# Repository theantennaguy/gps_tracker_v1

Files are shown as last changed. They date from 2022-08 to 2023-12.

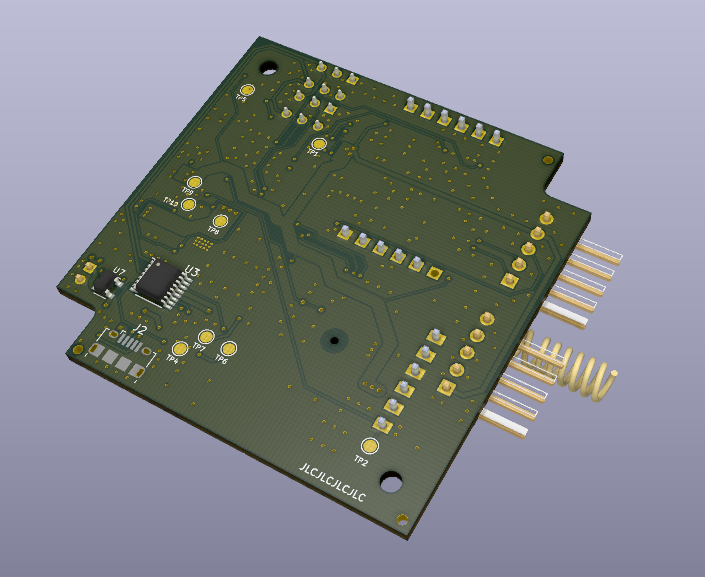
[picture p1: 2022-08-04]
hardware/images/2020-11-08_board_3.png

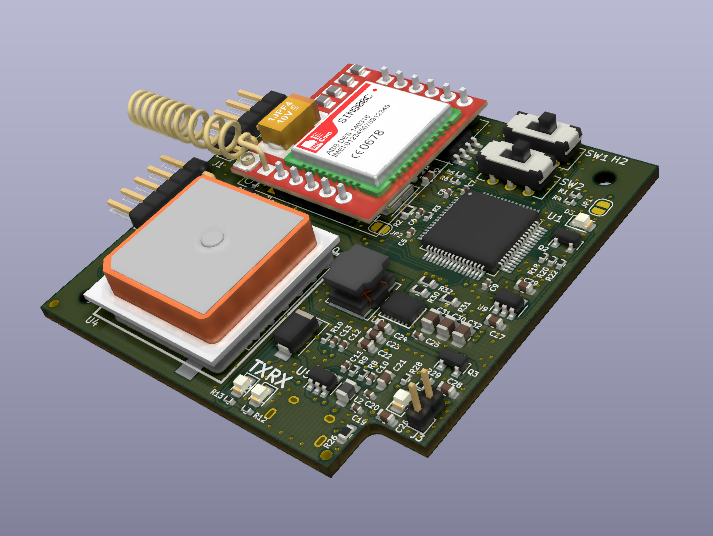
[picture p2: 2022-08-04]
hardware/images/2020-11-08_board_2.png

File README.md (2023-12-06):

# gps_tracker_v1
 
This project is discontinued. I'm working on a new version, but so far it's only in the design phase.

The hardware project for this project is complete and functional. A board-bring-up was sucessfully performed and all is operational. The code was never completed, only basic functions for capturing GPS coordinates and sending SMSs, but I never got ot finish a working application for it.

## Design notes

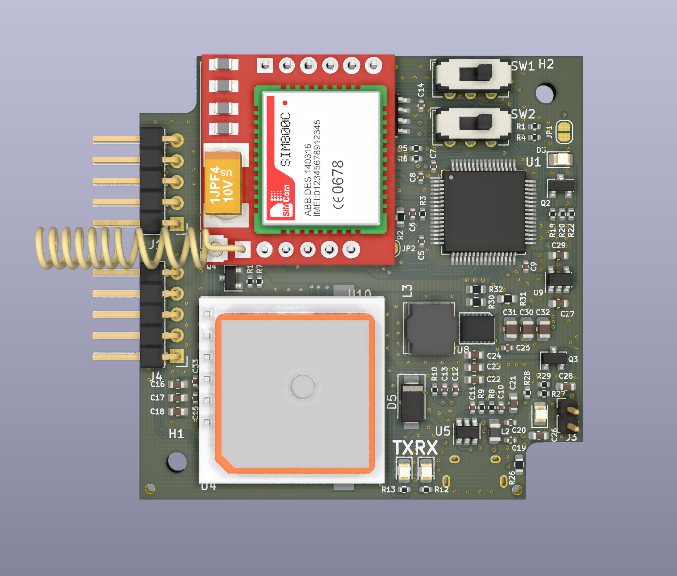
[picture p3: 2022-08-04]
hardware/images/2020-11-08_board.png

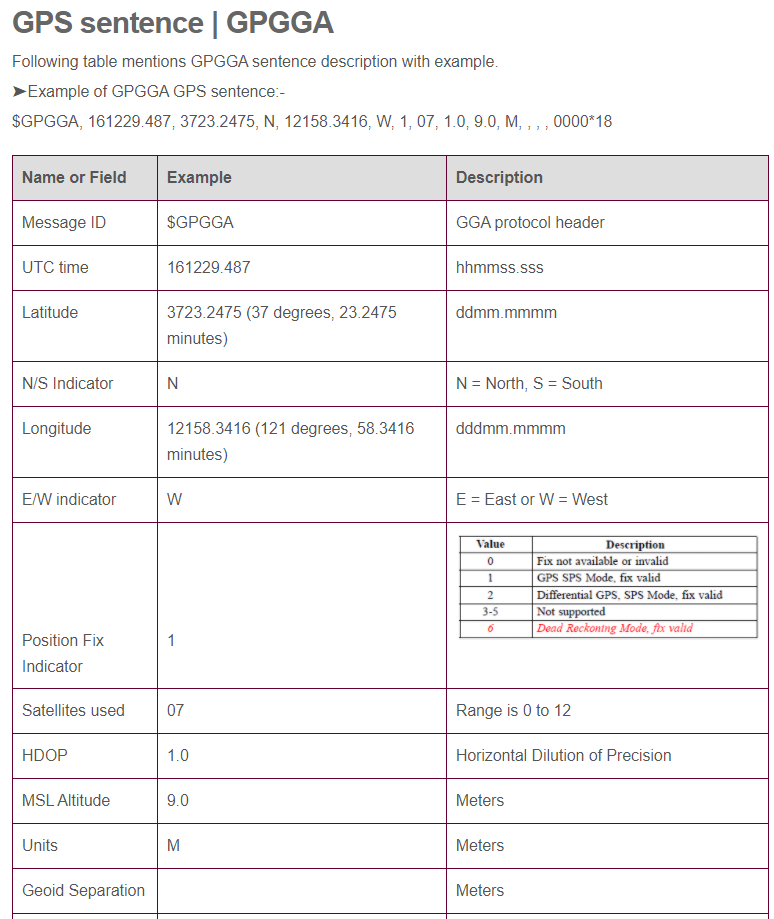
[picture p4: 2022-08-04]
hardware/pdf/GPGGA_message_structure.png

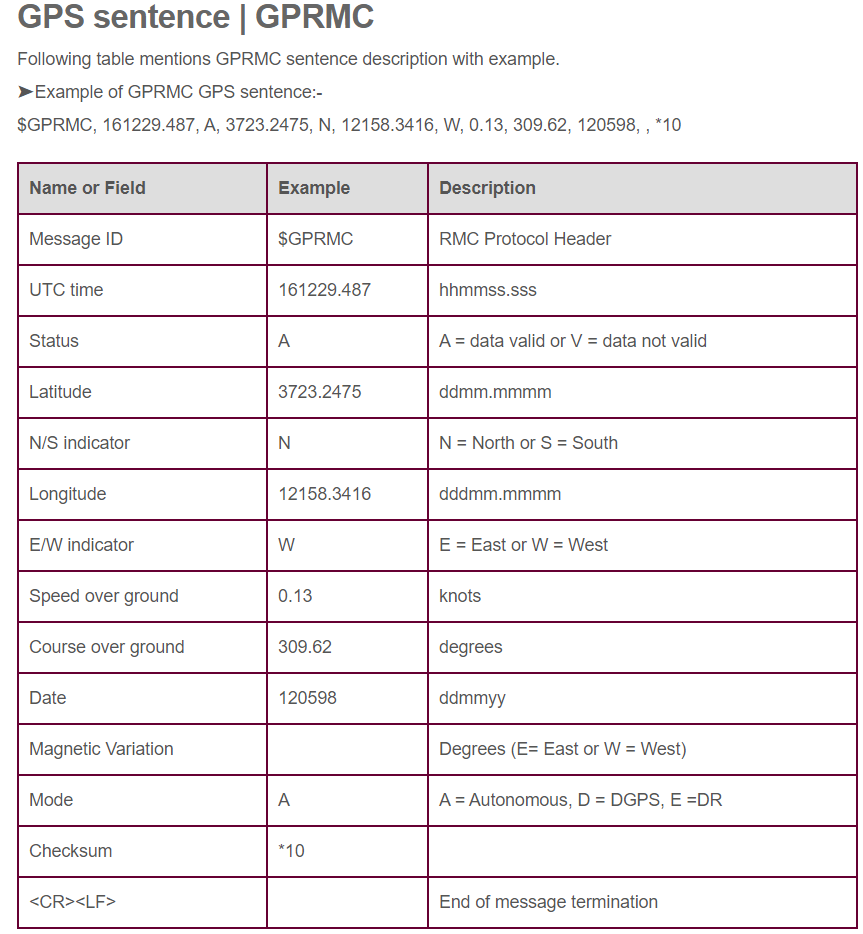
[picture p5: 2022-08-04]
hardware/pdf/GPRMC_message_structure.png

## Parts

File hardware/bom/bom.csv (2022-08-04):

Reference | Quantity | Value | Footprint | LCSC | Manufacturer | Mfr. PN | Supplier | Supplier PN
C1 C2 | 2 | 12pF | Capacitor_SMD:C_0402_1005Metric | C1547 | Guangdong Fenghua Advanced Tech | 0402CG120J500NT | LCSC | C1547
C10 C11 | 2 | 47pF | Capacitor_SMD:C_0402_1005Metric | C1567 | Guangdong Fenghua Advanced Tech | 0402CG470J500NT | LCSC | C1567
C5 C6 C7 C8 C9 C12 C13 C14 C15 C19 C20 C25 C33 | 13 | 100nF | Capacitor_SMD:C_0402_1005Metric | C1525 | Samsung Electro-Mechanics | CL05B104KO5NNNC | LCSC | C1525
C16 C17 C18 C22 C23 | 5 | 10uF | Capacitor_SMD:C_0603_1608Metric | C19702 | Samsung Electro-Mechanics | CL10A106KP8NNNC | LCSC | C19702
C3 C21 | 2 | 4.7uF | Capacitor_SMD:C_0603_1608Metric | C19666 | SAMSUNG | CL10A475KO8NNNC | LCSC | C19666
C30 C31 C32 | 3 | 22uF | Resistor_SMD:R_0805_2012Metric | C45783 | Samsung Electro-Mechanics | CL21A226MAQNNNE | LCSC | C45783
C4 C24 C26 C27 C28 C29 | 6 | 1uF | Capacitor_SMD:C_0603_1608Metric | C15849 | Samsung Electro-Mechanics | CL10A105KB8NNNC | LCSC | C15849
D1 | 1 | YELLOW | LED_SMD:LED_0805_2012Metric | C2296 | Hubei KENTO Elec | 17-21SUYC/TR8 | LCSC | C2296
D2 D3 D4 | 3 | RED | LED_SMD:LED_0805_2012Metric | C84256 | Foshan NationStar Optoelectronics | FC-2012HRK-620D | LCSC | C84256
D5 | 1 | SS14 | Diode_SMD:D_SMA | C2480 | MDD( Microdiode Electronics) | SS14 | LCSC | C2480
Q1 Q2 Q4 | 3 | S8050 | Package_TO_SOT_SMD:SOT-23 | C2146 | Changjiang Electronics Tech (CJ) | S8050 | LCSC | C2146
Q3 | 1 | Si2301CDS | Package_TO_SOT_SMD:SOT-23 | C10487 | Vishay Intertech | SI2301CDS-T1-GE3 | LCSC | C10487
R12 R13 R22 R27 | 4 | 330 | Resistor_SMD:R_0402_1005Metric | C25104 | Uniroyal Elec | 0402WGF3300TCE | LCSC | C25104
R4 R10 R14 R15 R23 R24 | 6 | 1k | Resistor_SMD:R_0402_1005Metric | C11702 | Uniroyal Elec | 0402WGF1001TCE | LCSC | C11702
R16 R25 | 2 | 5k6 | Resistor_SMD:R_0402_1005Metric | C25908 | Uniroyal Elec | 0402WGF5601TCE | LCSC | C25908
R7 R17 R18 | 3 | 4.7k | Resistor_SMD:R_0402_1005Metric | C25900 | Uniroyal Elec | 0402WGF4701TCE | LCSC | C25900
R11 R19 R20 | 3 | 47k | Resistor_SMD:R_0402_1005Metric | C25792 | Uniroyal Elec | 0402WGF4702TCE | LCSC | C25792
R1 R3 R5 R6 R21 R29 R33 | 7 | 10k | Resistor_SMD:R_0402_1005Metric | C25744 | Uniroyal Elec | 0402WGF1002TCE | LCSC | C25744
R26 | 1 | 100k | Resistor_SMD:R_0603_1608Metric | C25803 | Uniroyal Elec | 0603WAF1003T5E | LCSC | C25803
R28 | 1 | 2k | Resistor_SMD:R_0402_1005Metric | C4109 | Uniroyal Elec | 0402WGF2001TCE | LCSC | C4109
R31 | 1 | 150k | Resistor_SMD:R_0603_1608Metric | C22807 | Uniroyal Elec | 0603WAF1503T5E | LCSC | C22807
R30 R32 | 2 | 1M | Resistor_SMD:R_0603_1608Metric | C22935 | Uniroyal Elec | 0603WAF1004T5E | LCSC | C22935
U2 | 1 | CAT24C256 | Package_SO:SOIC-8_3.9x4.9mm_P1.27mm | C6482 | Microchip Tech | AT24C256C-SSHL-T | LCSC | C6482
U8 | 1 | TPS63020 | gps_tracker:QFN14_P0.5_4.15x3.15_wThermalVias | C15483 | Texas Instruments | TPS63020DSJR | LCSC | C15483

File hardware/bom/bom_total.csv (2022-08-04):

Reference | Quantity | Value | Footprint | LCSC | Manufacturer | Mfr. PN | Supplier | Supplier PN
C1 C2 | 2 | 12pF | Capacitor_SMD:C_0402_1005Metric | C1547 | Guangdong Fenghua Advanced Tech | 0402CG120J500NT | LCSC | C1547
C10 C11 | 2 | 47pF | Capacitor_SMD:C_0402_1005Metric | C1567 | Guangdong Fenghua Advanced Tech | 0402CG470J500NT | LCSC | C1567
C5 C6 C7 C8 C9 C12 C13 C14 C15 C19 C20 C25 C33 | 13 | 100nF | Capacitor_SMD:C_0402_1005Metric | C1525 | Samsung Electro-Mechanics | CL05B104KO5NNNC | LCSC | C1525
C16 C17 C18 C22 C23 | 5 | 10uF | Capacitor_SMD:C_0603_1608Metric | C19702 | Samsung Electro-Mechanics | CL10A106KP8NNNC | LCSC | C19702
C3 C21 | 2 | 4.7uF | Capacitor_SMD:C_0603_1608Metric | C19666 | Samsung Electro-Mechanics | CL10A475KO8NNNC | LCSC | C19666
C30 C31 C32 | 3 | 22uF | Resistor_SMD:R_0805_2012Metric | C45783 | Samsung Electro-Mechanics | CL21A226MAQNNNE | LCSC | C45783
C4 C24 C26 C27 C28 C29 | 6 | 1uF | Capacitor_SMD:C_0603_1608Metric | C15849 | Samsung Electro-Mechanics | CL10A105KB8NNNC | LCSC | C15849
D1 | 1 | YELLOW | LED_SMD:LED_0805_2012Metric | C2296 | Hubei KENTO Elec | 17-21SUYC/TR8 | LCSC | C2296
D2 D3 D4 | 3 | RED | LED_SMD:LED_0805_2012Metric | C84256 | Foshan NationStar Optoelectronics | FC-2012HRK-620D | LCSC | C84256
D5 | 1 | SS14 | Diode_SMD:D_SMA | C2480 | MDD( Microdiode Electronics) | SS14 | LCSC | C2480
H1 H2 | 2 | MountingHole | MountingHole:MountingHole_2.5mm
J1 J4 | 2 | Conn_01x05 | Connector_PinHeader_2.54mm:PinHeader_1x05_P2.54mm_Horizontal | - | - | -
J2 | 1 | USB_B_Micro | Connector_USB:USB_Micro-B_Amphenol_10118194_Horizontal | - | Amphenol | 10118194-0001LF | Mouser | 649-10118194-0001LF
J3 | 1 | Battery | Connector_PinHeader_2.00mm:PinHeader_1x02_P2.00mm_Vertical | - | - | -
JP1 JP2 | 2 | JP | Jumper:SolderJumper-2_P1.3mm_Open_RoundedPad1.0x1.5mm | - | - | -
L1 | 1 | 220 Ohm | Inductor_SMD:L_0603_1608Metric | C85826 | Murata Electronics | BLM18BB221SN1D | Mouser | 81-BLM18BB221SN1D
L2 | 1 | 330 Ohm | Inductor_SMD:L_0805_2012Metric | - | Murata Electronics | BLM21PG331SN1D | Mouser | 81-BLM21P331SG
L3 | 1 | 1.5uH | Inductor_SMD:L_Bourns_SRN6045TA | - | Bourns | SRN6045TA-1R5Y | Mouser | 652-SRN6045TA-1R5Y
Q1 Q2 Q4 | 3 | S8050 | Package_TO_SOT_SMD:SOT-23 | C2146 | Changjiang Electronics Tech (CJ) | S8050 | LCSC | C2146
Q3 | 1 | Si2301CDS | Package_TO_SOT_SMD:SOT-23 | C10487 | Vishay Intertech | SI2301CDS-T1-GE3 | LCSC | C10487
R12 R13 R22 R27 | 4 | 330 | Resistor_SMD:R_0402_1005Metric | C25104 | Uniroyal Elec | 0402WGF3300TCE | LCSC | C25104
R4 R10 R14 R15 R23 R24 | 6 | 1k | Resistor_SMD:R_0402_1005Metric | C11702 | Uniroyal Elec | 0402WGF1001TCE | LCSC | C11702
R16 R25 | 2 | 5k6 | Resistor_SMD:R_0402_1005Metric | C25908 | Uniroyal Elec | 0402WGF5601TCE | LCSC | C25908
R7 R17 R18 | 3 | 4.7k | Resistor_SMD:R_0402_1005Metric | C25900 | Uniroyal Elec | 0402WGF4701TCE | LCSC | C25900
R11 R19 R20 | 3 | 47k | Resistor_SMD:R_0402_1005Metric | C25792 | Uniroyal Elec | 0402WGF4702TCE | LCSC | C25792
R1 R3 R5 R6 R21 R29 R33 | 7 | 10k | Resistor_SMD:R_0402_1005Metric | C25744 | Uniroyal Elec | 0402WGF1002TCE | LCSC | C25744
R26 | 1 | 100k | Resistor_SMD:R_0603_1608Metric | C25803 | Uniroyal Elec | 0603WAF1003T5E | LCSC | C25803
R28 | 1 | 2k | Resistor_SMD:R_0402_1005Metric | C4109 | Uniroyal Elec | 0402WGF2001TCE | LCSC | C4109
R31 | 1 | 150k | Resistor_SMD:R_0603_1608Metric | C22807 | Uniroyal Elec | 0603WAF1503T5E | LCSC | C22807
R30 R32 | 2 | 1M | Resistor_SMD:R_0603_1608Metric | C22935 | Uniroyal Elec | 0603WAF1004T5E | LCSC | C22935
R8 R9 | 2 | 27 | Resistor_SMD:R_0402_1005Metric | - | YAGEO | RT0402FRE0727RL | Mouser | 603-RT0402FRE0727R
SW1 SW2 | 2 | SW_Push_DPDT | Button_Switch_THT:SW_CuK_JS202011CQN_DPDT_Straight | - | C&K | JS202011JCQN | Mouser | 611-JS202011JCQN
TP1 | 1 | 3V3_MCU | TestPoint:TestPoint_Pad_D1.5mm | -
TP10 | 1 | PGOOD | TestPoint:TestPoint_Pad_D1.5mm | -
TP2 | 1 | PPS | TestPoint:TestPoint_Pad_D1.5mm | -
TP4 TP5 | 2 | GND | TestPoint:TestPoint_Pad_D1.5mm | -
TP6 | 1 | USB | TestPoint:TestPoint_Pad_D1.5mm | -
TP7 | 1 | 5V0 | TestPoint:TestPoint_Pad_D1.5mm | -
TP8 | 1 | 4V0 | TestPoint:TestPoint_Pad_D1.5mm | -
TP9 | 1 | 3V3 | TestPoint:TestPoint_Pad_D1.5mm | -
U1 | 1 | STM32F030R8Tx | Package_QFP:LQFP-64_10x10mm_P0.5mm | C39105 | STMicroelectronics | STM32F030R8T6 | Mouser | -
U10 | 1 | L80-RE | gps_tracker:L80RE | - | Quectel | L80RE-M37 | Mouser | 277-L80RE-M37
U2 | 1 | CAT24C256 | Package_SO:SOIC-8_3.9x4.9mm_P1.27mm | C6482 | Microchip Tech | AT24C256C-SSHL-T | LCSC | C6482
U3 | 1 | FT230XS | Package_SO:SSOP-16_3.9x4.9mm_P0.635mm | - | FTDI | FT230XS | Mouser | 895-FT230XS-R
U4 | 1 | UP501B | gps_tracker:UP501B | - | Fastrax | UP501B | Mouser | -
U5 | 1 | USBLC6 | Package_TO_SOT_SMD:SOT-23-6 | C7519 | STMicroelectronics | USBLC6-2SC6 | Mouser | 511-USBLC6-2SC6
U6 | 1 | SIM800L | gps_tracker:SIM_800L_breakout | - | SIM | SIM800L | - | -
U7 | 1 | MCP73812T-420I-OT | Package_TO_SOT_SMD:SOT-23-5 | C144308 | Microchip Tech | MCP73812T-420I/OT | Mouser | 579-MCP73812T-420IOT
U8 | 1 | TPS63020 | gps_tracker:QFN14_P0.5_4.15x3.15_wThermalVias | C15483 | Texas Instruments | TPS63020DSJR | Mouser | 595-TPS63020DSJR
U9 | 1 | LP5907MFX-3.3 | Package_TO_SOT_SMD:SOT-23-5 | C80670 | Texas Instruments | LP5907MFX-3.3/NOPB | Mouser | 595-LP5907QMFX-3.3Q1
Y1 | 1 | 8 MHz | Crystal:Crystal_SMD_5032-2Pin_5.0x3.2mm | - | ECS | ECS-80-12-30Q-DS-TR | Mouser | 520-80-12-30Q-DST

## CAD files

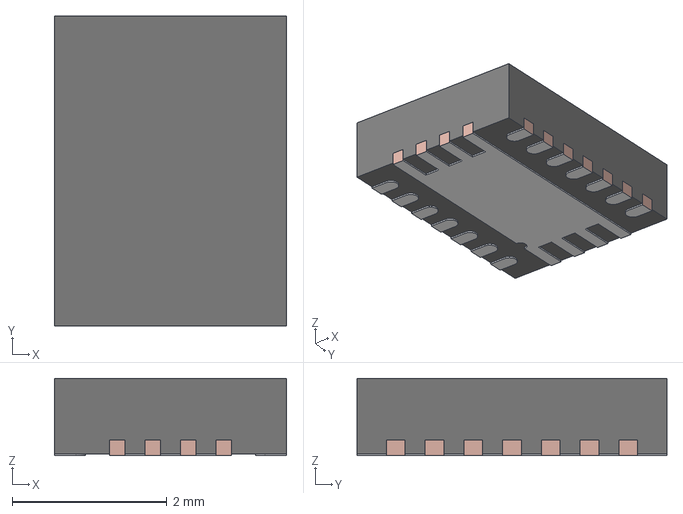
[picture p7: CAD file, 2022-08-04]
hardware/3d_models/DSJ0014A.stp
3.00 x 4.00 x 1.00 mm
FRAME
MOLD

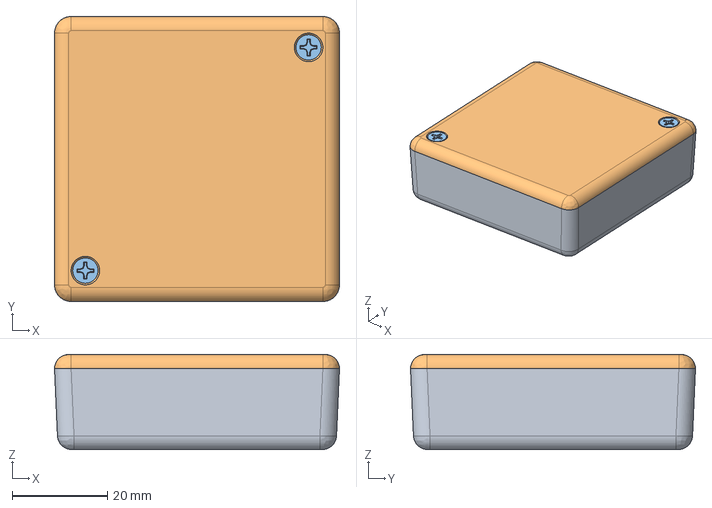
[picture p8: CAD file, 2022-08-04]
hardware/3d_models/1551TTBU.stp
60.0 x 60.0 x 20.0 mm
1551T Box
1551T Lid

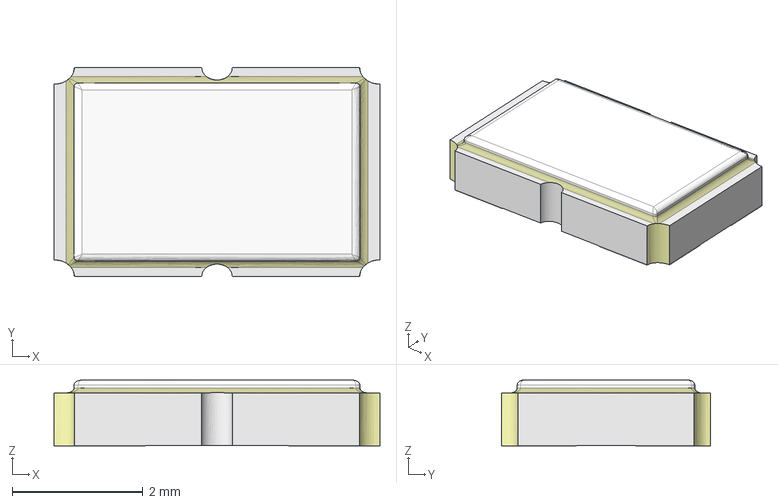
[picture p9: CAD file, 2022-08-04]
hardware/3d_models/xtal_osc_5x3.2.step
4.99 x 3.20 x 1.01 mm

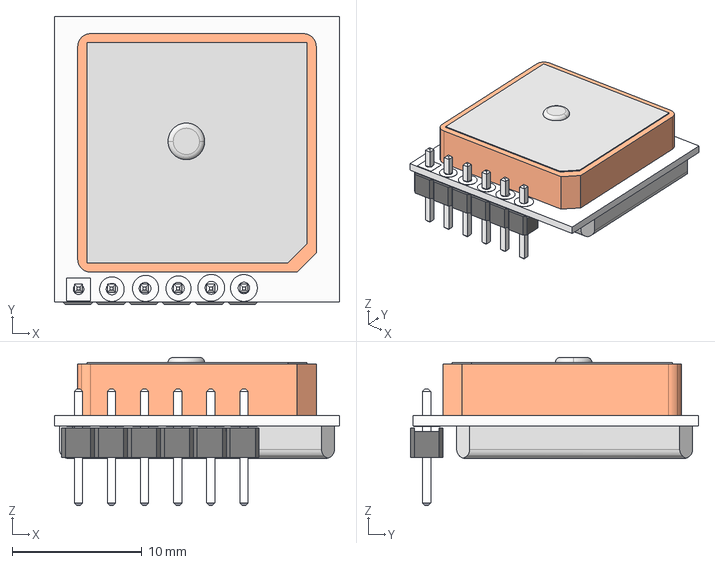
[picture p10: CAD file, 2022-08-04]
hardware/3d_models/fastrax_up501b.step
22.0 x 22.2 x 11.4 mm

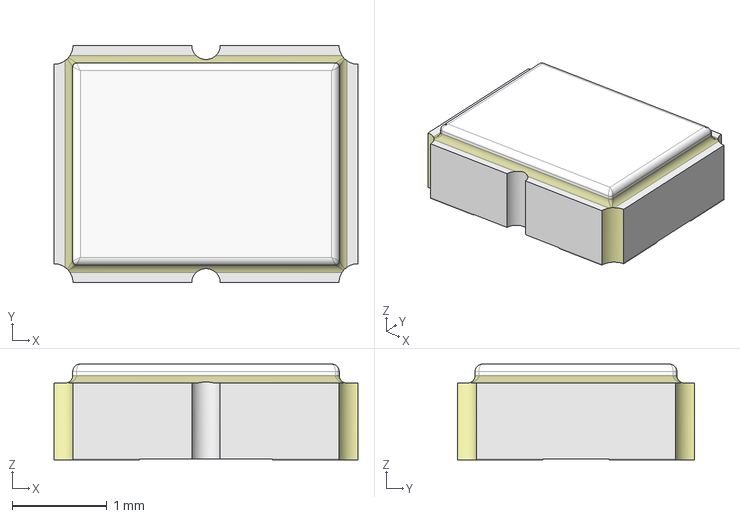
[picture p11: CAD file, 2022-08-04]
hardware/3d_models/xtal_osc_3.2x2.5.step
3.20 x 2.50 x 1.01 mm

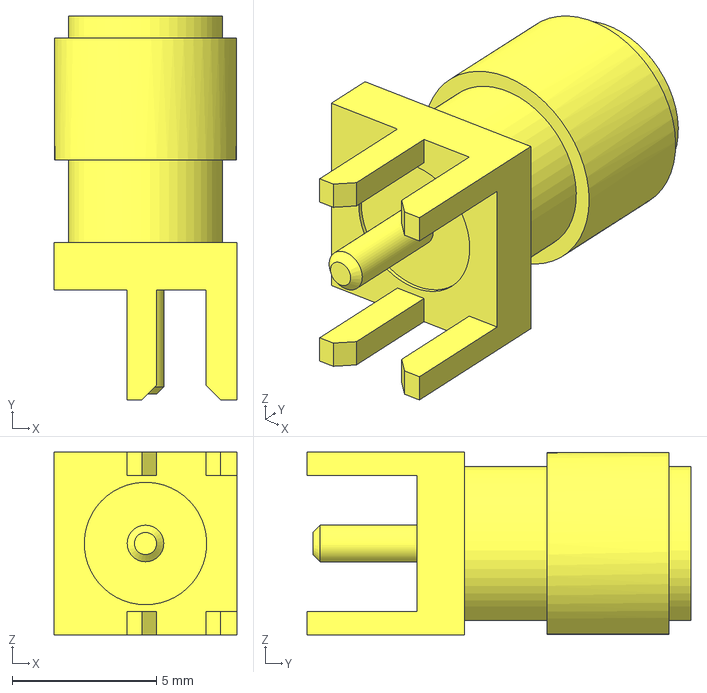
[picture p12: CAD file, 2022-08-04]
hardware/3d_models/SMA-J-P-H-ST-EM1.stp
6.35 x 13.3 x 6.35 mm

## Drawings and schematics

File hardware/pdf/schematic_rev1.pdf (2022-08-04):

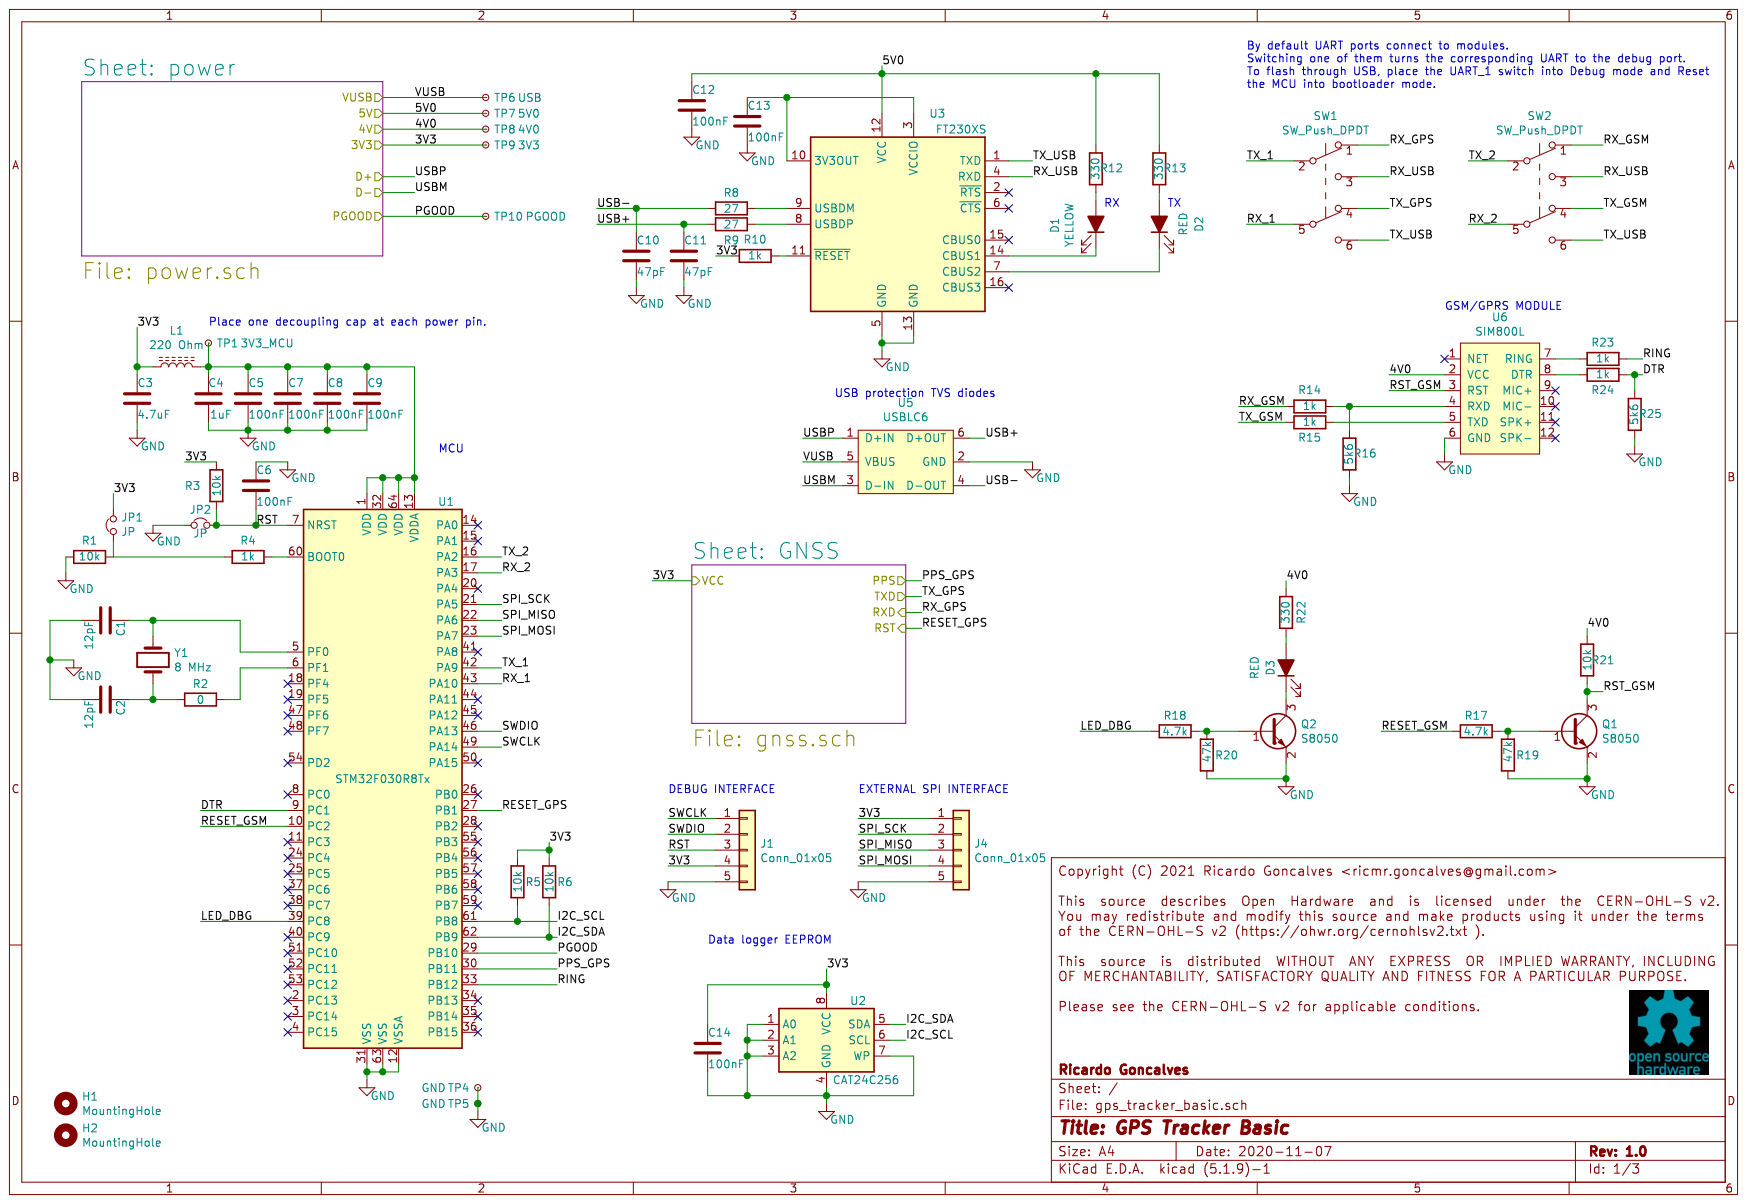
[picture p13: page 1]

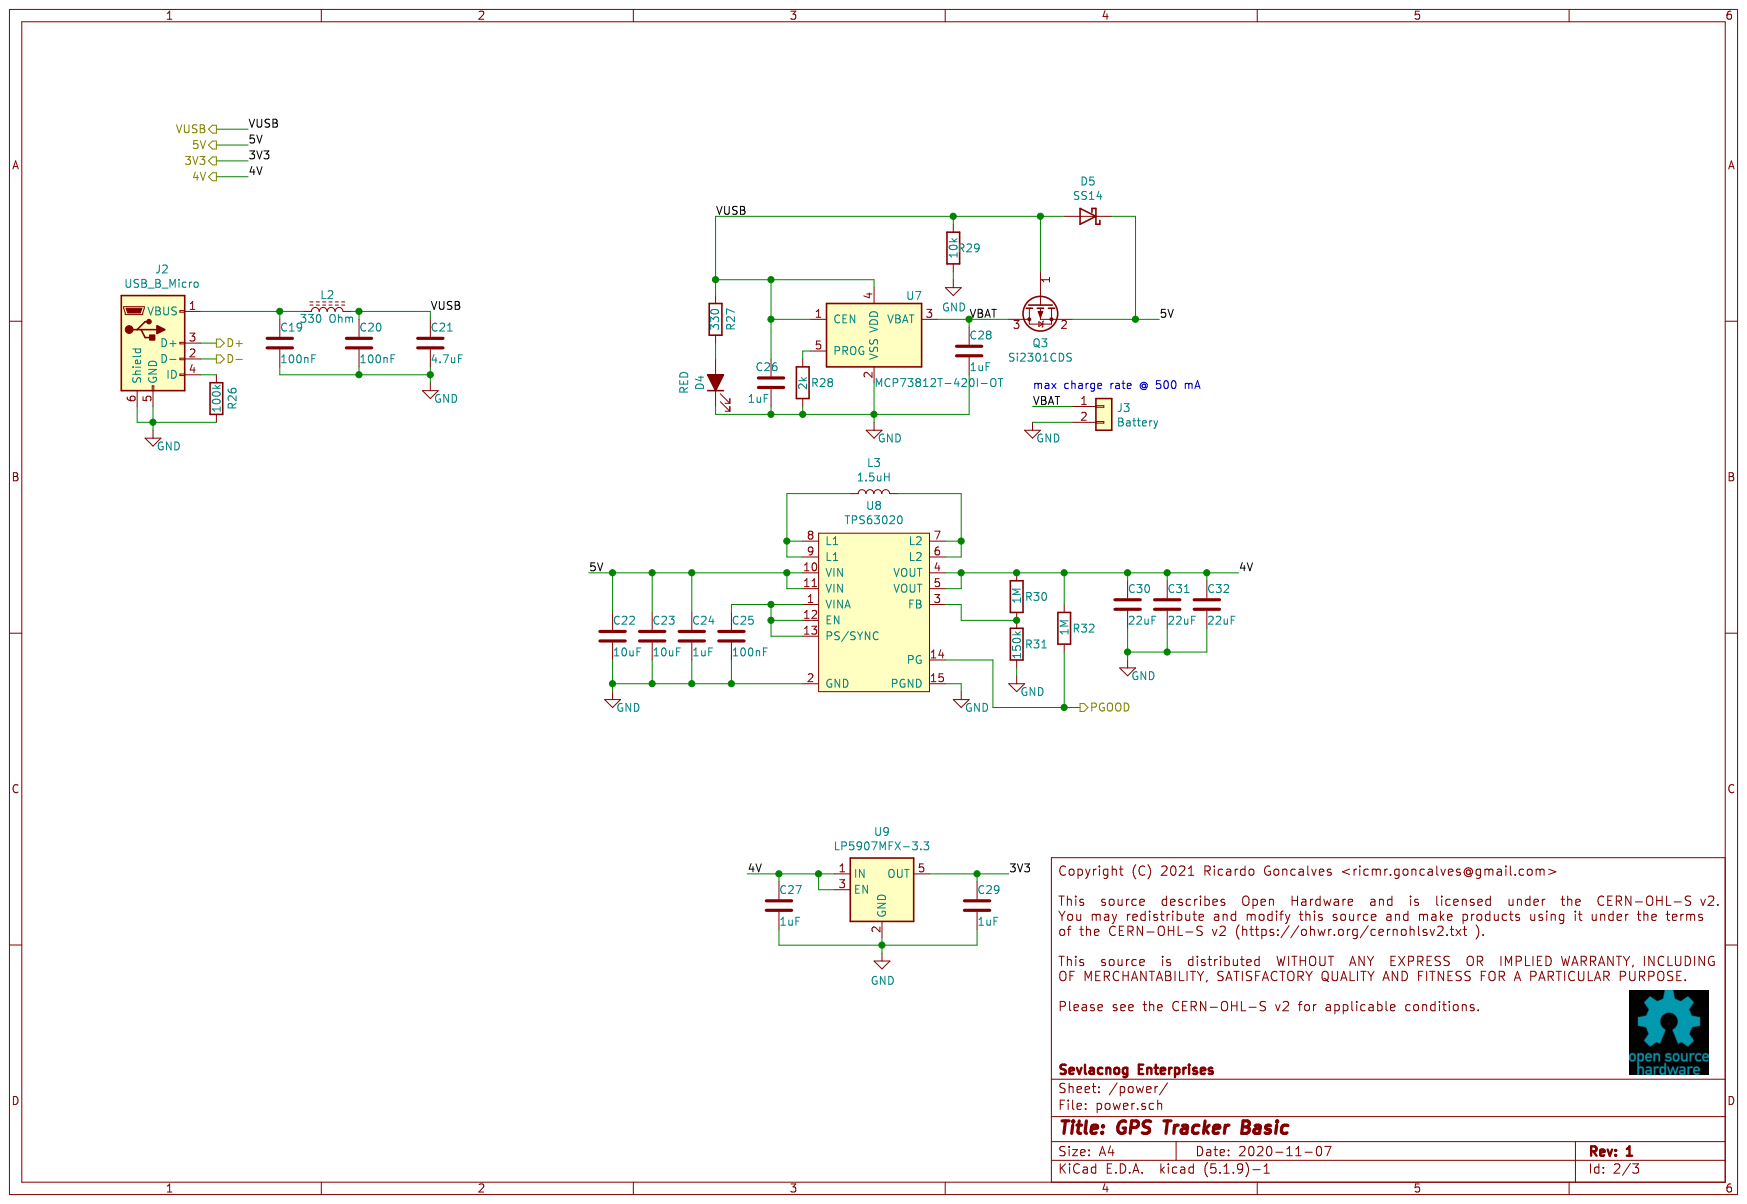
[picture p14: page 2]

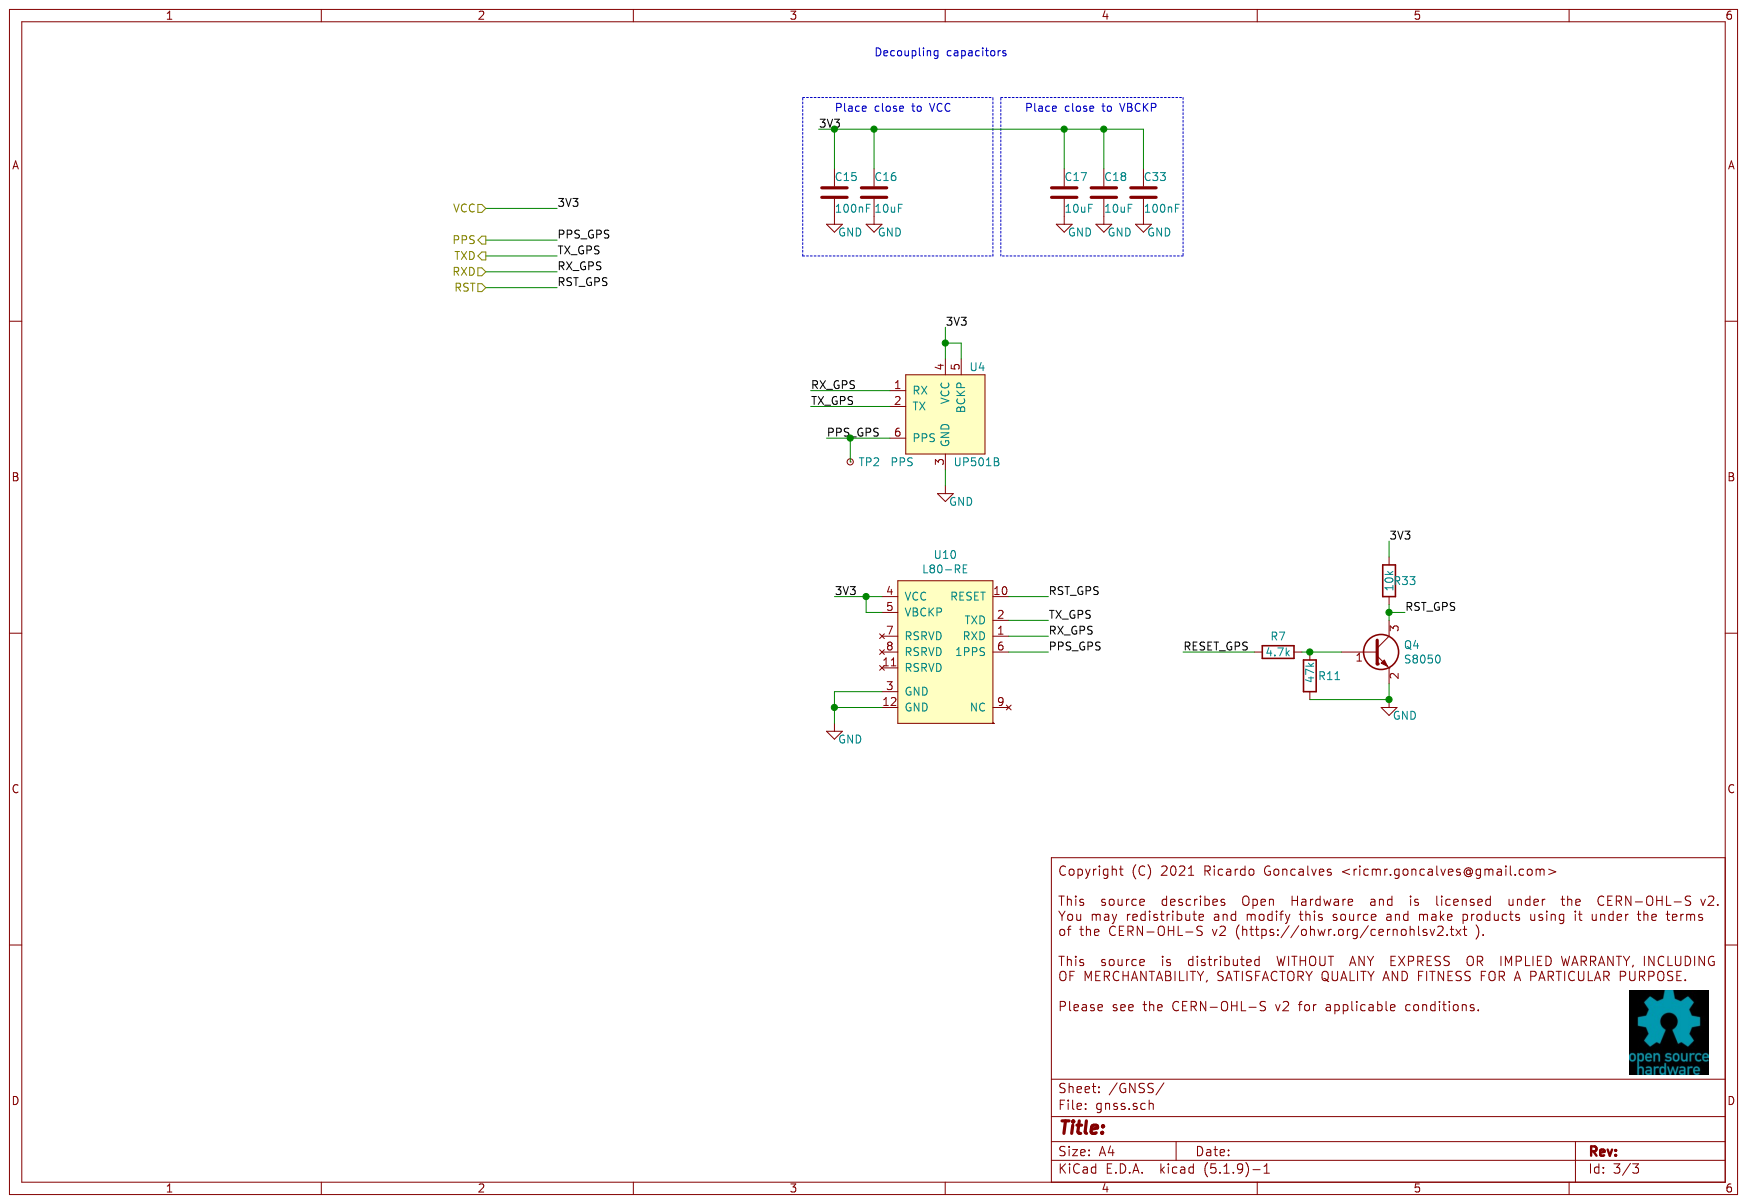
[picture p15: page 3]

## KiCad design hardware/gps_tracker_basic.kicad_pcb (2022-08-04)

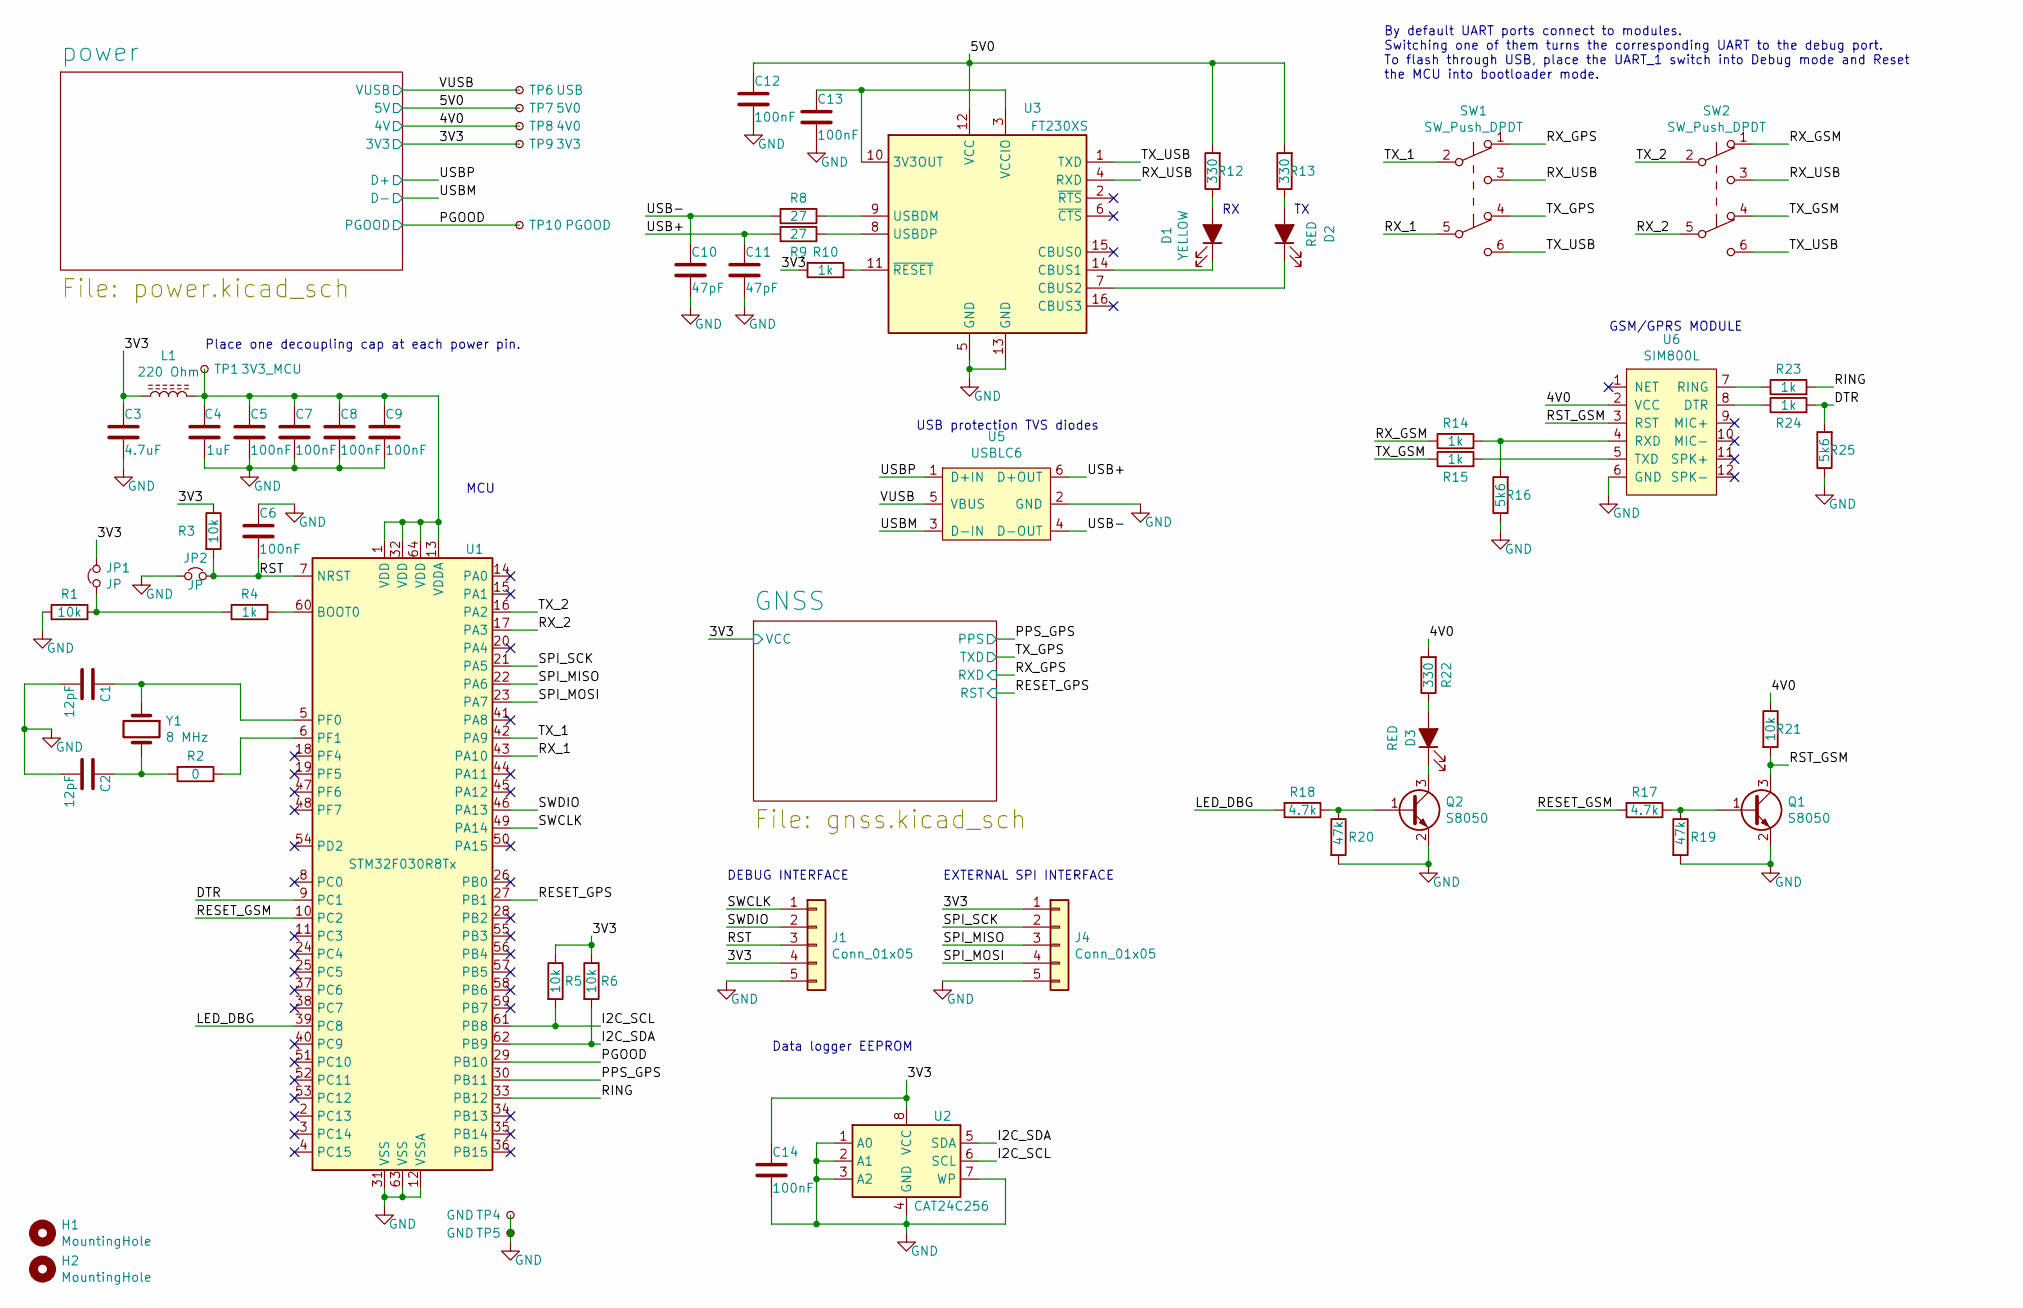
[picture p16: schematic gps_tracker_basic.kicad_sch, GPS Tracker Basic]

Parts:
C1, C2: 12pF; C_0402_1005Metric; Mfr. PN 0402CG120J500NT; LCSC C1547
C3: 4.7uF; C_0603_1608Metric; Mfr. PN CL10A475KO8NNNC; LCSC C19666
C4: 1uF; C_0603_1608Metric; Mfr. PN CL10A105KB8NNNC; LCSC C15849
C5, C6, C7, C8, C9, C12, C13, C14: 100nF; C_0402_1005Metric; Mfr. PN CL05B104KO5NNNC; LCSC C1525
C10, C11: 47pF; C_0402_1005Metric; Mfr. PN 0402CG470J500NT; LCSC C1567
D1: YELLOW; LED_0805_2012Metric; Mfr. PN 17-21SUYC/TR8; LCSC C2296
D2, D3: RED; LED_0805_2012Metric; Mfr. PN FC-2012HRK-620D; LCSC C84256
H1, H2: MountingHole; MountingHole_2.5mm
J1, J4: Conn_01x05; PinHeader_1x05_P2.54mm_Horizontal
JP1, JP2: JP; SolderJumper-2_P1.3mm_Open_RoundedPad1.0x1.5mm
L1: 220 Ohm; L_0603_1608Metric; Mfr. PN BLM18BB221SN1D; LCSC C85826
Q1, Q2: S8050; SOT-23; Mfr. PN S8050; LCSC C2146
R1, R3, R5, R6, R21: 10k; R_0402_1005Metric; Mfr. PN 0402WGF1002TCE; LCSC C25744
R2: 0; R_0603_1608Metric
R4, R10, R14, R15, R23, R24: 1k; R_0402_1005Metric; Mfr. PN 0402WGF1001TCE; LCSC C11702
R8, R9: 27; R_0402_1005Metric; Mfr. PN RT0402FRE0727RL
R12, R13, R22: 330; R_0402_1005Metric; Mfr. PN 0402WGF3300TCE; LCSC C25104
R16, R25: 5k6; R_0402_1005Metric; Mfr. PN 0402WGF5601TCE; LCSC C25908
R17, R18: 4.7k; R_0402_1005Metric; Mfr. PN 0402WGF4701TCE; LCSC C25900
R19, R20: 47k; R_0402_1005Metric; Mfr. PN 0402WGF4702TCE; LCSC C25792
SW1, SW2: SW_Push_DPDT; SW_CuK_JS202011CQN_DPDT_Straight; Mfr. PN JS202011JCQN
TP1: 3V3_MCU; TestPoint_Pad_D1.5mm
TP4, TP5: GND; TestPoint_Pad_D1.5mm
TP6: USB; TestPoint_Pad_D1.5mm
TP7: 5V0; TestPoint_Pad_D1.5mm
TP8: 4V0; TestPoint_Pad_D1.5mm
TP9: 3V3; TestPoint_Pad_D1.5mm
TP10: PGOOD; TestPoint_Pad_D1.5mm
U1: STM32F030R8Tx; LQFP-64_10x10mm_P0.5mm; Mfr. PN STM32F030R8T6; LCSC C39105
U2: CAT24C256; SOIC-8_3.9x4.9mm_P1.27mm; Mfr. PN AT24C256C-SSHL-T; LCSC C6482
U3: FT230XS; SSOP-16_3.9x4.9mm_P0.635mm; Mfr. PN FT230XS
U5: USBLC6; SOT-23-6; Mfr. PN USBLC6-2SC6; LCSC C7519
U6: SIM800L; SIM_800L_breakout; Mfr. PN SIM800L
Y1: 8 MHz; Crystal_SMD_5032-2Pin_5.0x3.2mm; Mfr. PN ECS-80-12-30Q-DS-TR

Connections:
/3V3: C3.1, C14.1, J1.4, J4.1, JP1.2, L1.1, R3.1, R5.1, R6.1, R10.1, TP9.1, U2.8 (VCC); also elsewhere on the board
/4V0: R21.1, R22.2, TP8.1, U6.2 (VCC); also elsewhere on the board
/5V0: C12.1, R12.2, R13.2, TP7.1, U3.12 (VCC); also elsewhere on the board
/DTR: R24.2, R25.2, U1.9 (PC1)
/I2C_SCL: R5.2, U1.61 (PB8), U2.6 (SCL)
/I2C_SDA: R6.2, U1.62 (PB9), U2.5 (SDA)
/LED_DBG: R18.2, U1.39 (PC8)
/PGOOD: TP10.1, U1.29 (PB10); also elsewhere on the board
/PPS_GPS: U1.30 (PB11); also elsewhere on the board
/RESET_GPS: U1.27 (PB1); also elsewhere on the board
/RESET_GSM: R17.2, U1.10 (PC2)
/RING: R23.2, U1.33 (PB12)
/RST: C6.2, J1.3, JP2.2, R3.2, U1.7 (NRST); also elsewhere on the board
/RST_GSM: Q1.3 (C), R21.2, U6.3 (RST)
/RX_1: SW1.5 (B), U1.43 (PA10)
/RX_2: SW2.5 (B), U1.17 (PA3)
/RX_GPS: SW1.1 (A); also elsewhere on the board
/RX_GSM: R14.1, SW2.1 (A)
/RX_USB: SW1.3 (C), SW2.3 (C), U3.4 (RXD)
/SPI_MISO: J4.3, U1.22 (PA6)
/SPI_MOSI: J4.4, U1.23 (PA7)
/SPI_SCK: J4.2, U1.21 (PA5)
/SWCLK: J1.1, U1.49 (PA14)
/SWDIO: J1.2, U1.46 (PA13)
/TX_1: SW1.2 (B), U1.42 (PA9)
/TX_2: SW2.2 (B), U1.16 (PA2)
/TX_GPS: SW1.4 (A); also elsewhere on the board
/TX_GSM: R15.1, SW2.4 (A)
/TX_USB: SW1.6 (C), SW2.6 (C), U3.1 (TXD)
/USB+: C11.1, R9.2, U5.6 (D+OUT)
/USB-: C10.1, R8.2, U5.4 (D-OUT)
/USBM: U5.3 (D-IN); also elsewhere on the board
/USBP: U5.1 (D+IN); also elsewhere on the board
/VUSB: TP6.1, U5.5 (VBUS); also elsewhere on the board
GND: C1.2, C2.2, C3.2, C4.2, C5.2, C6.1, C7.2, C8.2, C9.2, C10.2, C11.2, C12.2, C13.2, C14.2, J1.5, J4.5, JP2.1, Q1.2 (E), Q2.2 (E), R1.1, R16.1, R19.2, R20.2, R25.1, TP4.1, TP5.1, U1.12 (VSSA), U1.31 (VSS), U1.63 (VSS), U2.1 (A0), U2.2 (A1), U2.3 (A2), U2.4 (GND), U2.7 (WP), U3.5 (GND), U3.13 (GND), U5.2 (GND), U6.6 (GND); also elsewhere on the board
unnamed: C1.1, U1.5 (PF0), Y1.1
unnamed: C2.1, R2.2, Y1.2
unnamed: C4.1, C5.1, C7.1, C8.1, C9.1, L1.2, TP1.1, U1.1 (VDD), U1.13 (VDDA), U1.32 (VDD), U1.64 (VDD)
unnamed: C13.1, U3.3 (VCCIO), U3.10 (3V3OUT)
unnamed: D1.1 (K), U3.14 (CBUS1)
unnamed: D1.2 (A), R12.1
unnamed: D2.1 (K), U3.7 (CBUS2)
unnamed: D2.2 (A), R13.1
unnamed: D3.1 (K), Q2.3 (C)
unnamed: D3.2 (A), R22.1
unnamed 51: JP1.1, R1.2, R4.1; also elsewhere on the board
unnamed: Q1.1 (B), R17.1, R19.1
unnamed: Q2.1 (B), R18.1, R20.1
unnamed: R2.1, U1.6 (PF1)
unnamed: R4.2, U1.60 (BOOT0)
unnamed: R8.1, U3.9 (USBDM)
unnamed: R9.1, U3.8 (USBDP)
unnamed: R10.2, U3.11 (~RESET)
unnamed: R14.2, R16.2, U6.4 (RXD)
unnamed: R15.2, U6.5 (TXD)
unnamed: R23.1, U6.7 (RING)
unnamed: R24.1, U6.8 (DTR)

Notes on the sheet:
Place one decoupling cap at each power pin.
By default UART ports connect to modules. Switching one of them turns the corresponding UART to the debug port. To flash through USB, place the UART_1 switch into Debug mode and Reset the MCU into bootloader mode.
DEBUG INTERFACE
USB protection TVS diodes
EXTERNAL SPI INTERFACE
MCU
Data logger EEPROM
GSM/GPRS MODULE

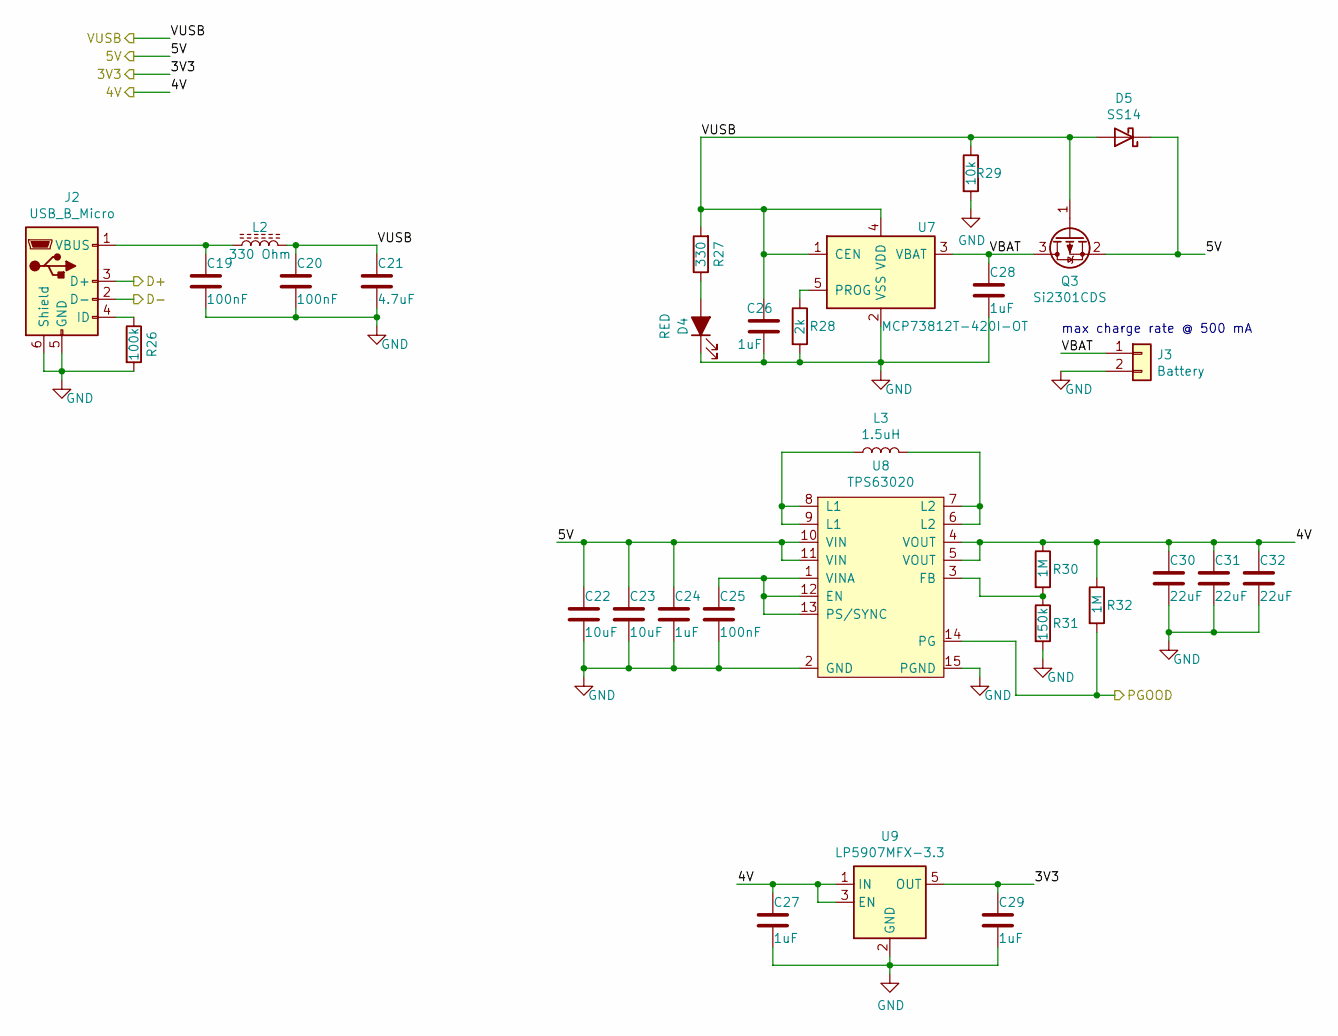
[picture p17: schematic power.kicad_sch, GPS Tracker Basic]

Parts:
C19, C20, C25: 100nF; C_0402_1005Metric; Mfr. PN CL05B104KO5NNNC; LCSC C1525
C21: 4.7uF; C_0603_1608Metric; Mfr. PN CL10A475KO8NNNC; LCSC C19666
C22, C23: 10uF; C_0603_1608Metric; Mfr. PN CL10A106KP8NNNC; LCSC C19702
C24, C26, C27, C28, C29: 1uF; C_0603_1608Metric; Mfr. PN CL10A105KB8NNNC; LCSC C15849
C30, C31, C32: 22uF; C_0805_2012Metric; Mfr. PN CL21A226MAQNNNE; LCSC C45783
D4: RED; LED_0805_2012Metric; Mfr. PN FC-2012HRK-620D; LCSC C84256
D5: SS14; D_SMA; Mfr. PN SS14; LCSC C2480
J2: USB_B_Micro; USB_Micro-B_Amphenol_10118194_Horizontal; Mfr. PN 10118194-0001LF
J3: Battery; PinHeader_1x02_P2.00mm_Vertical
L2: 330 Ohm; L_0805_2012Metric; Mfr. PN BLM21PG331SN1D
L3: 1.5uH; L_Bourns_SRN6045TA; Mfr. PN SRN6045TA-1R5Y
Q3: Si2301CDS; SOT-23; Mfr. PN SI2301CDS-T1-GE3; LCSC C10487
R26: 100k; R_0603_1608Metric; Mfr. PN 0603WAF1003T5E; LCSC C25803
R27: 330; R_0402_1005Metric; Mfr. PN 0402WGF3300TCE; LCSC C25104
R28: 2k; R_0402_1005Metric; Mfr. PN 0402WGF2001TCE; LCSC C4109
R29: 10k; R_0402_1005Metric; Mfr. PN 0402WGF1002TCE; LCSC C25744
R30, R32: 1M; R_0603_1608Metric; Mfr. PN 0603WAF1004T5E; LCSC C22935
R31: 150k; R_0603_1608Metric; Mfr. PN 0603WAF1503T5E; LCSC C22807
U7: MCP73812T-420I-OT; SOT-23-5; Mfr. PN MCP73812T-420I/OT; LCSC C144308
U8: TPS63020; QFN14_P0.5_4.15x3.15_wThermalVias; Mfr. PN TPS63020DSJR; LCSC C15483
U9: LP5907MFX-3.3; SOT-23-5; Mfr. PN LP5907MFX-3.3/NOPB; LCSC C80670

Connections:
/3V3: C29.1, U9.5 (OUT); also elsewhere on the board
/4V0: C27.1, C30.1, C31.1, C32.1, R30.1, R32.1, U8.4 (VOUT), U8.5 (VOUT), U9.1 (IN), U9.3 (EN); also elsewhere on the board
/5V0: C22.1, C23.1, C24.1, D5.1 (K), Q3.2 (S), U8.10 (VIN), U8.11 (VIN); also elsewhere on the board
/PGOOD: R32.2, U8.14 (PG); also elsewhere on the board
/USBM: J2.2 (D-); also elsewhere on the board
/USBP: J2.3 (D+); also elsewhere on the board
/VUSB: C20.1, C21.1, C26.1, D5.2 (A), L2.2, Q3.1 (G), R27.2, R29.1, U7.1 (CEN), U7.4 (VDD); also elsewhere on the board
/power/VBAT: C28.1, J3.1, Q3.3 (D), U7.3 (VBAT)
GND: C19.2, C20.2, C21.2, C22.2, C23.2, C24.2, C25.2, C26.2, C27.2, C28.2, C29.2, C30.2, C31.2, C32.2, D4.1 (K), J2.5 (GND), J2.6 (Shield), J3.2, R26.2, R28.2, R29.2, R31.2, U7.2 (VSS), U8.2 (GND), U8.15 (PGND), U9.2 (GND); also elsewhere on the board
unnamed: C19.1, J2.1 (VBUS), L2.1
unnamed: C25.1, U8.1 (VINA), U8.12 (EN), U8.13 (PS/SYNC)
unnamed: D4.2 (A), R27.1
unnamed: J2.4 (ID), R26.1
unnamed: L3.1, U8.8 (L1), U8.9 (L1)
unnamed: L3.2, U8.6 (L2), U8.7 (L2)
unnamed: R28.1, U7.5 (PROG)
unnamed: R30.2, R31.1, U8.3 (FB)

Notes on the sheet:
max charge rate @ 500 mA

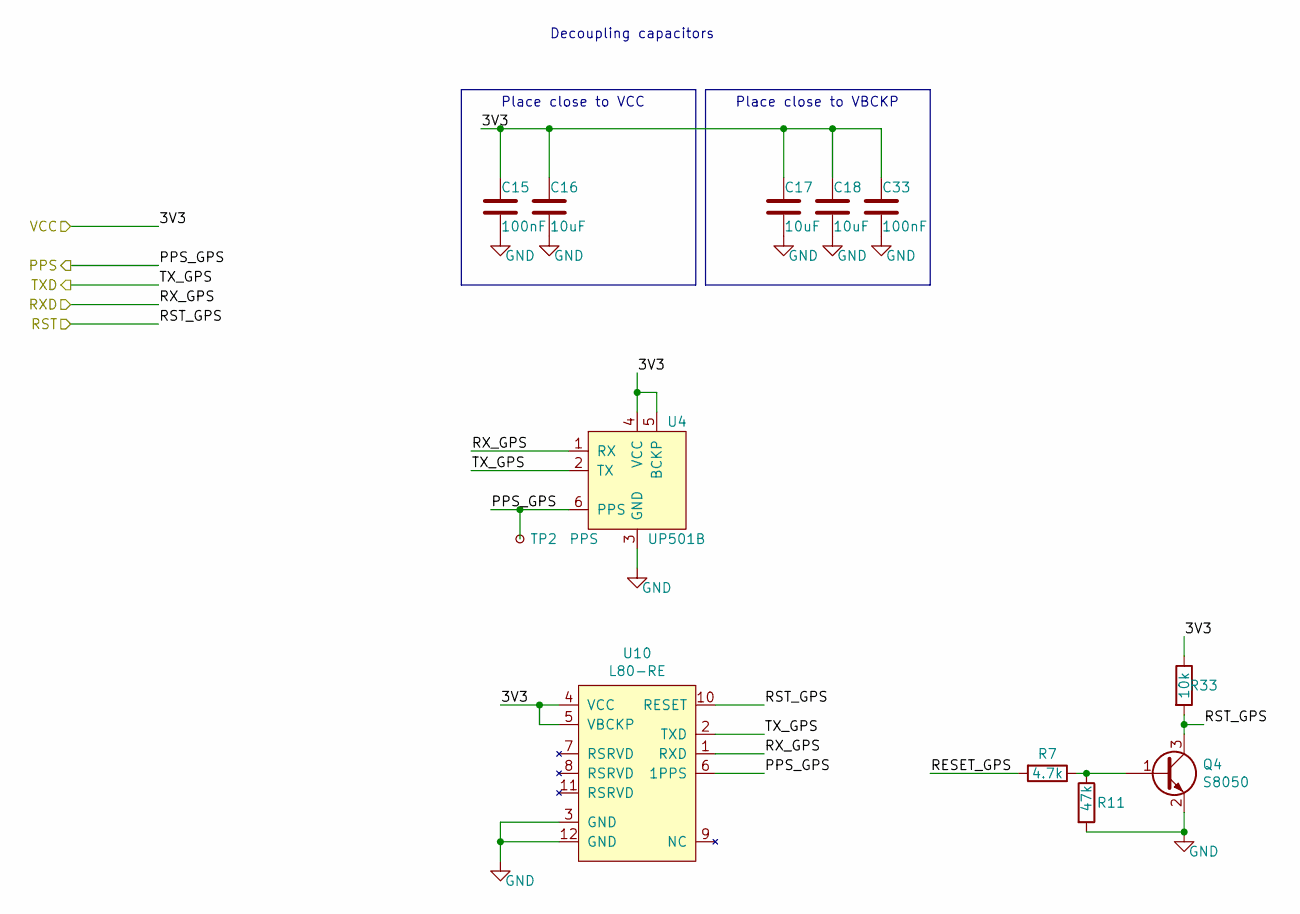
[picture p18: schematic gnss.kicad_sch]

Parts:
C15, C33: 100nF; C_0402_1005Metric; Mfr. PN CL05B104KO5NNNC; LCSC C1525
C16, C17, C18: 10uF; C_0603_1608Metric; Mfr. PN CL10A106KP8NNNC; LCSC C19702
Q4: S8050; SOT-23; Mfr. PN S8050; LCSC C2146
R7: 4.7k; R_0402_1005Metric; Mfr. PN 0402WGF4701TCE; LCSC C25900
R11: 47k; R_0402_1005Metric; Mfr. PN 0402WGF4702TCE; LCSC C25792
R33: 10k; R_0402_1005Metric; Mfr. PN 0402WGF1002TCE; LCSC C25744
TP2: PPS; TestPoint_Pad_D1.5mm
U4: UP501B; Mfr. PN UP501B
U10: L80-RE; L80RE; Mfr. PN L80RE-M37

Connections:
/3V3: C15.1, C16.1, C17.1, C18.1, C33.1, R33.1, U4.4 (VCC), U4.5 (BCKP), U10.4 (VCC), U10.5 (VBCKP); also elsewhere on the board
/GNSS/RESET_GPS: R7.2
/PPS_GPS: TP2.1, U4.6 (PPS), U10.6 (1PPS); also elsewhere on the board
/RESET_GPS: Q4.3 (C), R33.2, U10.10 (RESET); also elsewhere on the board
/RX_GPS: U4.1 (RX), U10.1 (RXD); also elsewhere on the board
/TX_GPS: U4.2 (TX), U10.2 (TXD); also elsewhere on the board
GND: C15.2, C16.2, C17.2, C18.2, C33.2, Q4.2 (E), R11.2, U4.3 (GND), U10.3 (GND), U10.12 (GND); also elsewhere on the board
unnamed: Q4.1 (B), R7.1, R11.1

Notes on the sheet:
Place close to VBCKP
Place close to VCC
Decoupling capacitors

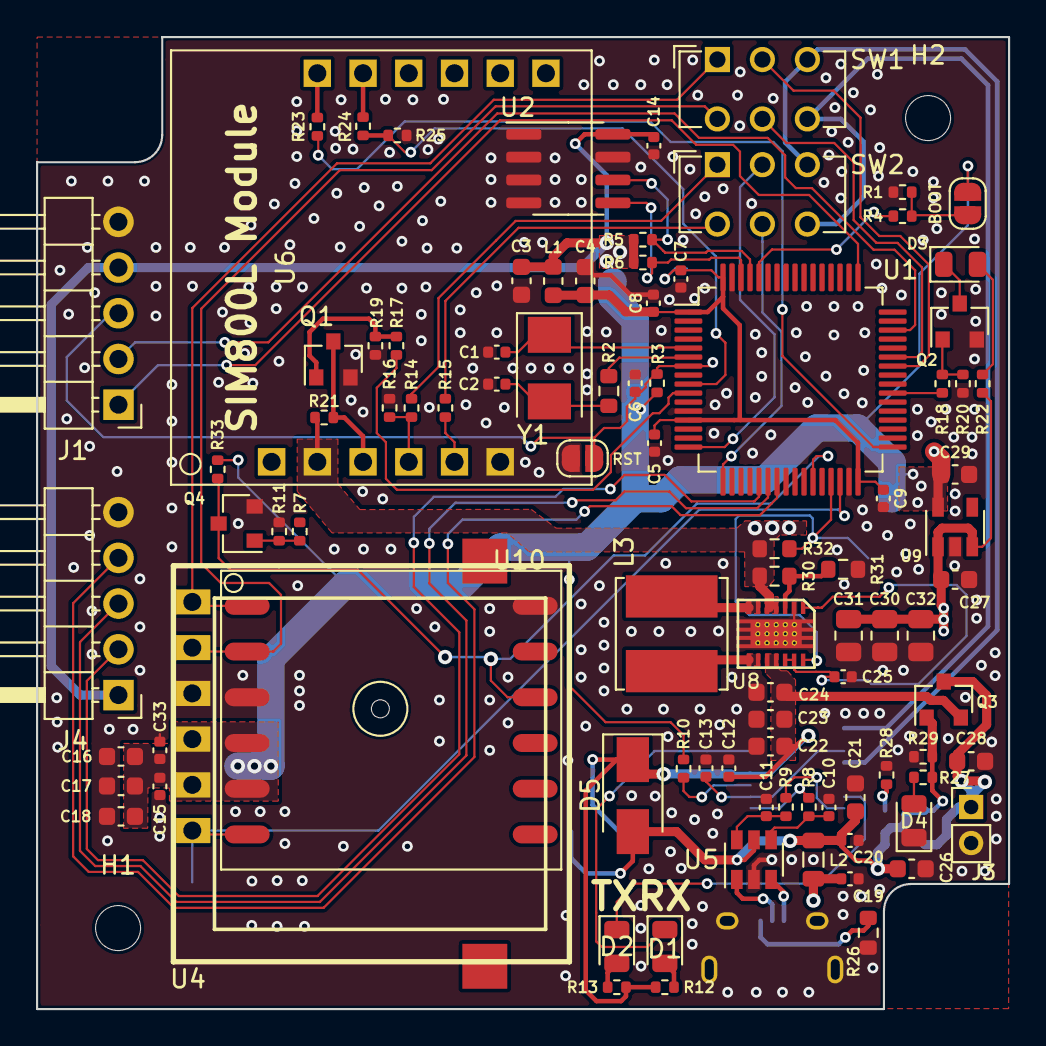
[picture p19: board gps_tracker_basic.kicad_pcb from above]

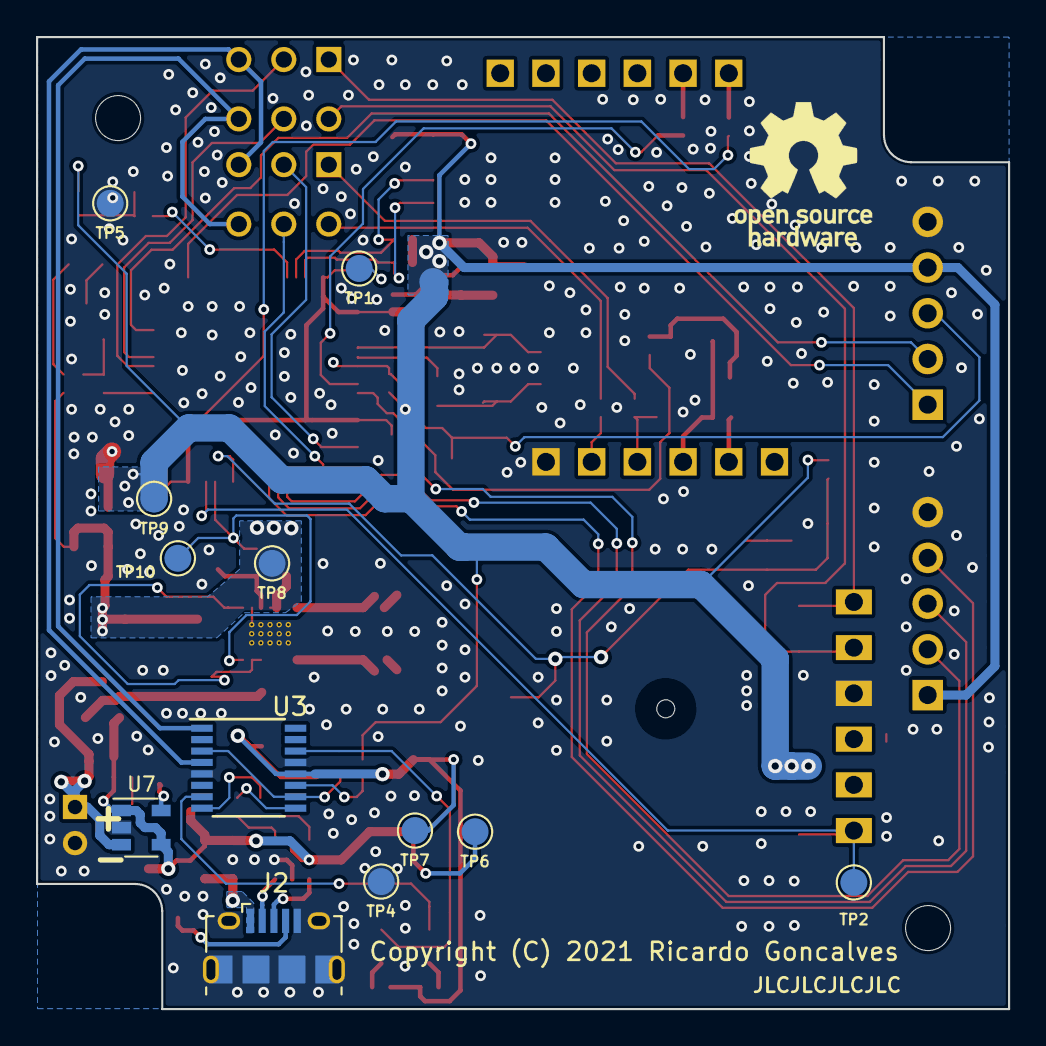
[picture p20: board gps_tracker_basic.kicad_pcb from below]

Board: 2 copper layers, 54.0 x 54.0 mm, 108 parts (12 on the bottom side), 67 nets.

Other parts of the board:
BOOT: JP; SolderJumper-2_P1.3mm_Open_RoundedPad1.0x1.5mm
RST: JP; SolderJumper-2_P1.3mm_Open_RoundedPad1.0x1.5mm

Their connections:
/3V3: BOOT.2; also elsewhere on the board
/RST: RST.2; also elsewhere on the board
GND: RST.1; also elsewhere on the board
unnamed 51: BOOT.1; also elsewhere on the board

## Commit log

2022-08-04 create repository
    crate repository with project initial data of project.
    [1551TTBU.stp, DSJ0014A.stp, SMA-J-P-H-ST-EM1.stp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]
2022-08-04 Update kicad sheets
    [gnss.kicad_sch, gps_tracker_basic.kicad_pcb, gps_tracker_basic.kicad_sch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]

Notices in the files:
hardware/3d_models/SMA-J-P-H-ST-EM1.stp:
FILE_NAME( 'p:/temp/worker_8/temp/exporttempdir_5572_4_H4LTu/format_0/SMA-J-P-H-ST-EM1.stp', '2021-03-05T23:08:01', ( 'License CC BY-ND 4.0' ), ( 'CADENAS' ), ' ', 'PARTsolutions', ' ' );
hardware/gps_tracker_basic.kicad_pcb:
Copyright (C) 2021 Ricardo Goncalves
